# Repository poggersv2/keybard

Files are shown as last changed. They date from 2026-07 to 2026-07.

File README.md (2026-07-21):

# keybard (it's not misspelt)

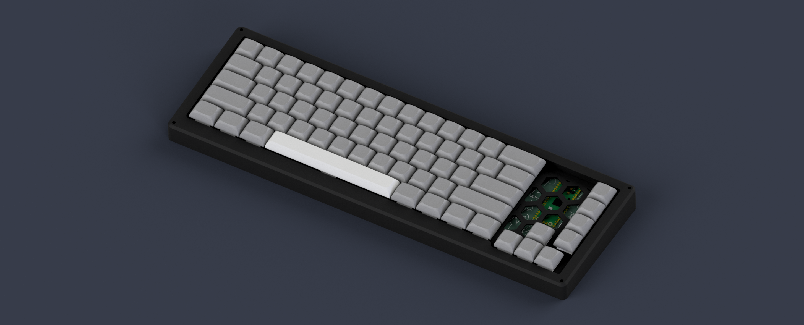
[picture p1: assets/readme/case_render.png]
Keybard


## Overview
**keybard** is a custom mechanical keyboard designed for Hackclub Keeb. Its a modified 60% layout, extended with a dedicated arrow key cluster and a column of macro keys on the side. 

The board is powered by a Raspberry Pi Pico (Orpheus Pico) and uses a sandwich mount case.

## Features
- **Layout:** Modified 60% + Arrow Keys + Macro Column
- **Microcontroller:** Raspberry Pi Pico / Orpheus Pico (RP2040)
- **Mounting Style:** Sandwich Mount
- **Firmware:** RMK with VIA support

## Why I Built It
Standard 60% keyboards are great for desk space but I wanted to have the arrow keys for productivity (and also games).

## What I Learned
Designing and building this board from scratch was kindda difficult: 

### 1. Switch Matrix 
Routing the matrix while making it look decent was hard.

### 2. Tolerances 
When designing the case, I found it hard to imagine the actual size of everything. The maths was a little hard to understand, but that got easier over time.

### 3. CAD
Before this project, I didn't really know how to use Fusion. I had to learn everything from scratch.

## Hardware Details

### Schematic
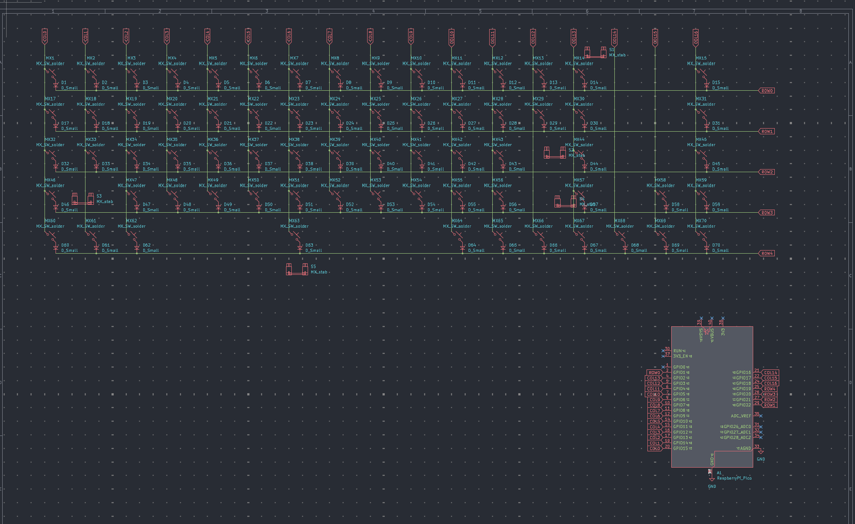
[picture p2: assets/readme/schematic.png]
Schematic


### PCB
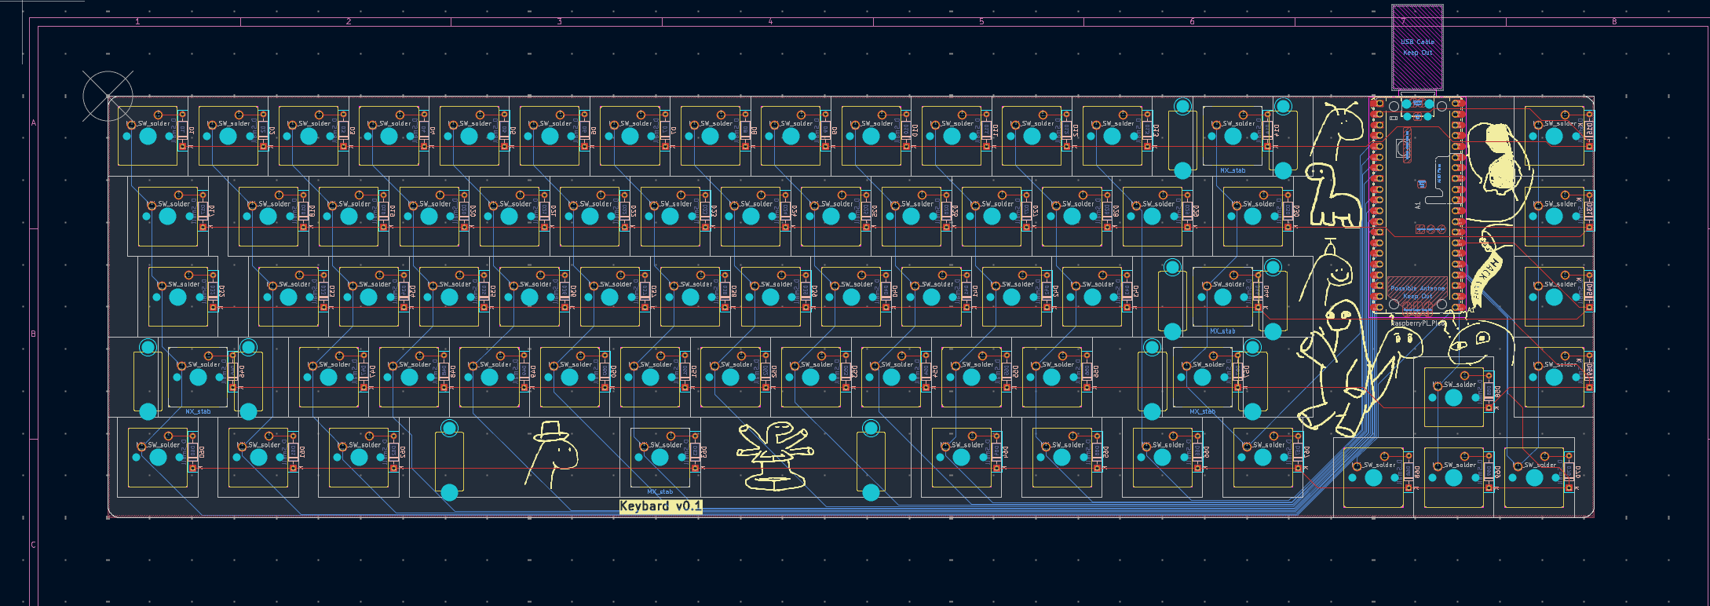
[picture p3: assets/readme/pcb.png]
PCB

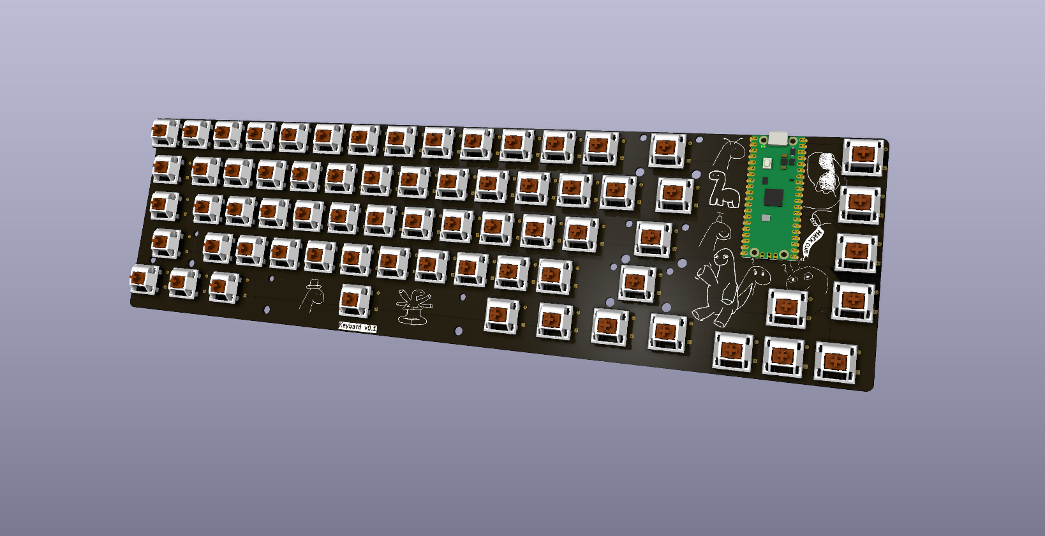
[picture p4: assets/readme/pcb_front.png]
PCB Front

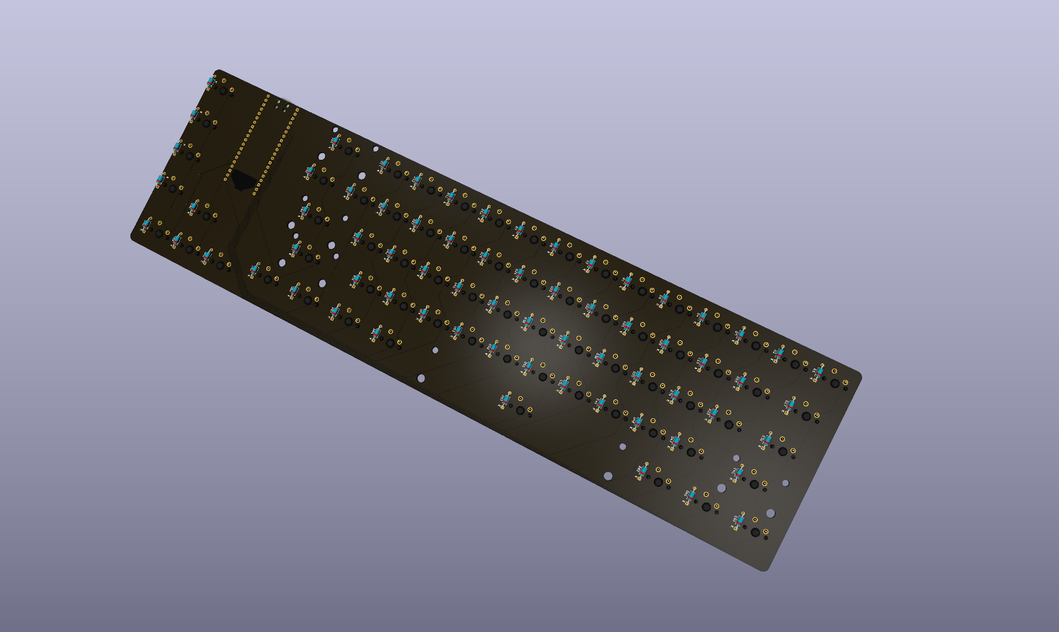
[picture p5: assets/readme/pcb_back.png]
PCB Back


### Case
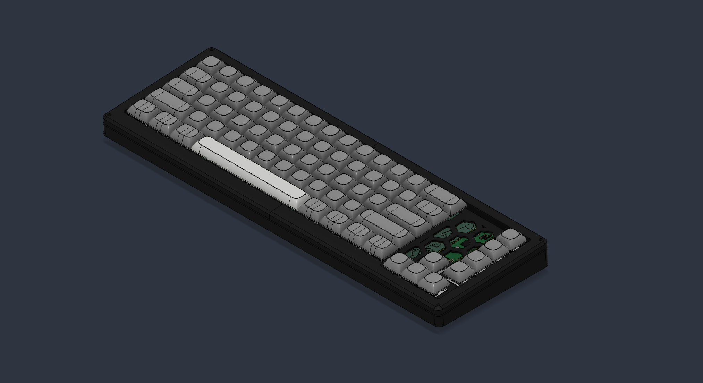
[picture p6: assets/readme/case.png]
Case


## Firmware
### How to Compile and Flash
### 1. Get the Firmware
1. Go to the **Actions** tab at the top of this GitHub repository.
2. Click on the latest successful run of the **Build RMK firmware** workflow.
3. Scroll down to the **Artifacts** section at the bottom of the page.
4. Download the compiled firmware `.zip` file and extract it to find your `.uf2` file.

### 2. Flash to the Keyboard
1. Unplug your keyboard.
2. Hold down the **BOOTSEL** button on your Raspberry Pi Pico.
3. While holding the button, plug the keyboard back into your computer via USB. 
4. A new mass storage drive will appear on your computer.
5. Drag and drop the `.uf2` firmware file into this drive.
6. The Pico will automatically reboot, and your keyboard is ready to use!

## Customization
### Keymap Editing (Vial)
This firmware is pre-configured with **Vial** , meaning you can remap your keys, setup macros, and change layers without needing to recompile firmware.

1. Download the Vial app or use the Web UI at [vial.rocks](https://vial.rocks/).
2. Plug in your keyboard and click **Authorize** (if using the web version) or let the app detect it.
3. Remap to your hearts content!

## Credits
* **Hack Club**
* **3D Models:** Cherry MX Switch model from [Thingiverse (2172302)](https://www.thingiverse.com/thing:2172302)
* **Layout Generation:** [Keyboard Tools Editor](https://editor.keyboard-tools.xyz/)
* **Firmware:** [RMK](https://rmk.rs/) and [Vial](https://vial.rocks/)

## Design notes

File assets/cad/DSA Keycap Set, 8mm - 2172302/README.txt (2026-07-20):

DSA Keycap Set, 8mm by kaelruland on Thingiverse: https://www.thingiverse.com/thing:2172302

Summary:
The new home of my DSA keycap project. This set includes 1u, 1u homing, 1.25u, 1.5u, 1.75u, 2u, 2.25u and 2.75u keys and a 6.25u spacebar. Mounts are standard MX. The 2u, 2.25u and 2.75u keys have three mounts spaced at 12mm from the center. The 6.25u spacebar has three mounts @ 50mm from the center. Mounts are flush with the bottom of the key so supports shouldn't be necessary. All keycaps are 18.2mm wide and n*(19mm) - 0.8mm long, where n is the unit length of the key. The height of the key is just under 8mm and the depth of the touch surface is 0.9mm below that. Minimum wall thickness is 1.8mm.

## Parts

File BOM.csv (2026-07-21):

Item | Quantity | Unit price (USD) | Price (USD) | Description/Specification | Source
Keycaps | 69 | $15.00 | $15.00 | Blank set of keycaps | https://www.aliexpress.com/item/1005005976474831.html?curPageLogUid=R90zIkfRGreX
Switches | 69 | $13.51 | $13.51 | Blue switches | https://www.aliexpress.com/item/1005002378701948.html?gatewayAdapt=usa2glo4itemAdapt
Diodes | 69 | $0.06 | $4.14 | 1N4148 | https://www.digikey.co.nz/en/products/detail/onsemi/1N4148/458603
Screws | 4 | $2.28 | $2.28 | M3 x 16mm | https://www.aliexpress.com/ssr/300000512/BundleDeals2?productIds=1005006904738286:12000058886763706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
Heatset Inserts | 4 | $5.85 | $5.85 | M3 x 5mm x 4mm | https://www.aliexpress.com/item/4000232858343.html?gatewayAdapt=usa2glo4itemAdapt&_randl_shipto=NZ
Microcontroller | 1 | 0 | $0.00 | Orpheus Pico
Stablizers | 1 | $4.35 | $4.35 | 4x 2U + 6.25U | https://www.aliexpress.com/item/1005004229140548.html?curPageLogUid=NnlyZwOGxuXr
 |  | Total (USD) | $45.13

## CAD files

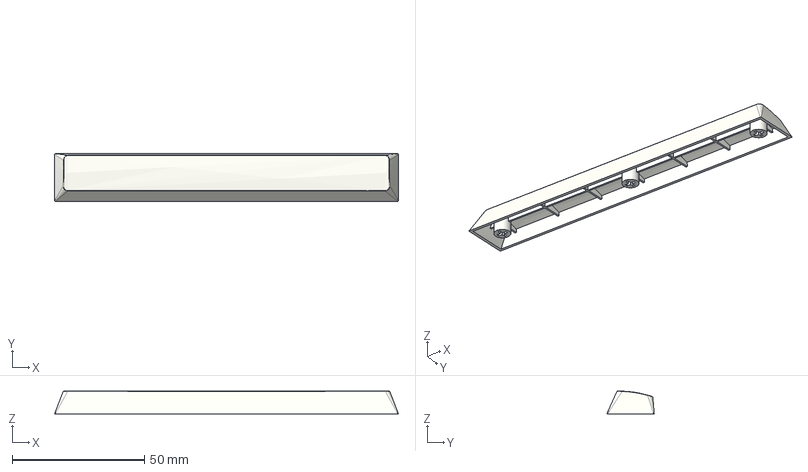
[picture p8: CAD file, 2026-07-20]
assets/cad/6.25U keycap.step
130.2 x 18.0 x 8.70 mm

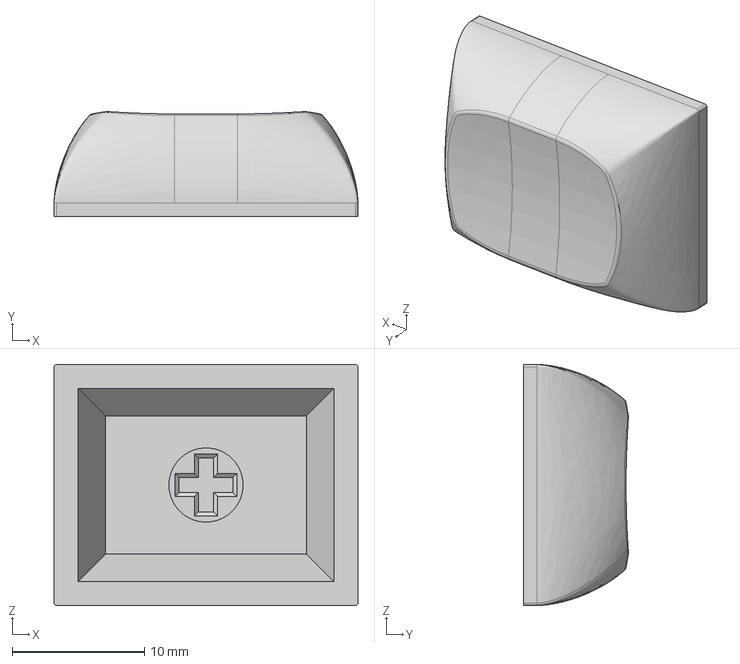
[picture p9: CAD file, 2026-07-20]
assets/cad/DSA Keycap Set, 8mm - 2172302/files/DSA_1.25u.step
22.9 x 7.91 x 18.2 mm

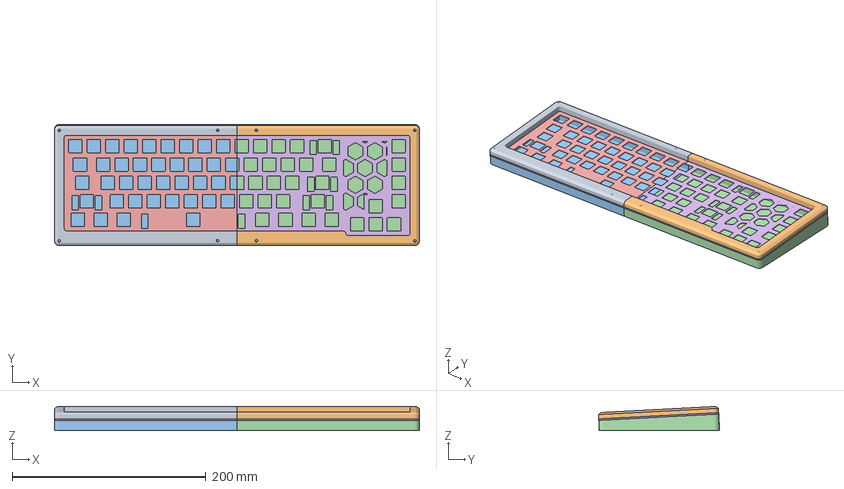
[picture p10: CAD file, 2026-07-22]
cad/case.3mf
376.4 x 124.9 x 24.8 mm
bezel (left)
bezel (right)
bottom (left)
bottom (right)
plate (left)
plate (right)

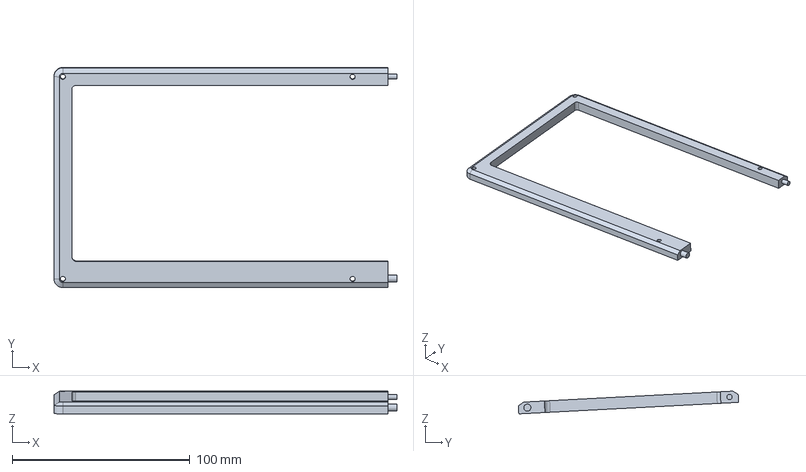
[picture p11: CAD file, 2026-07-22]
production/cad/left side/bezel(left).step
193.2 x 124.1 x 12.8 mm

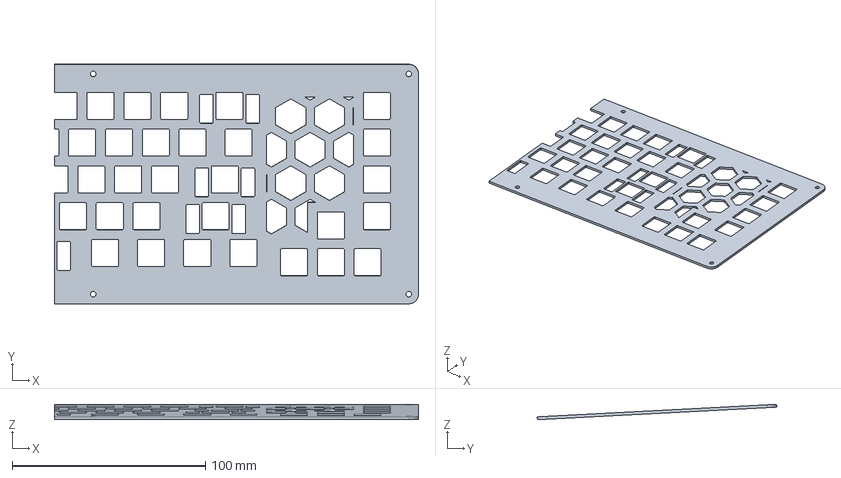
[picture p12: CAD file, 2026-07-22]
production/cad/right side/plate(right).step
188.2 x 123.9 x 7.99 mm

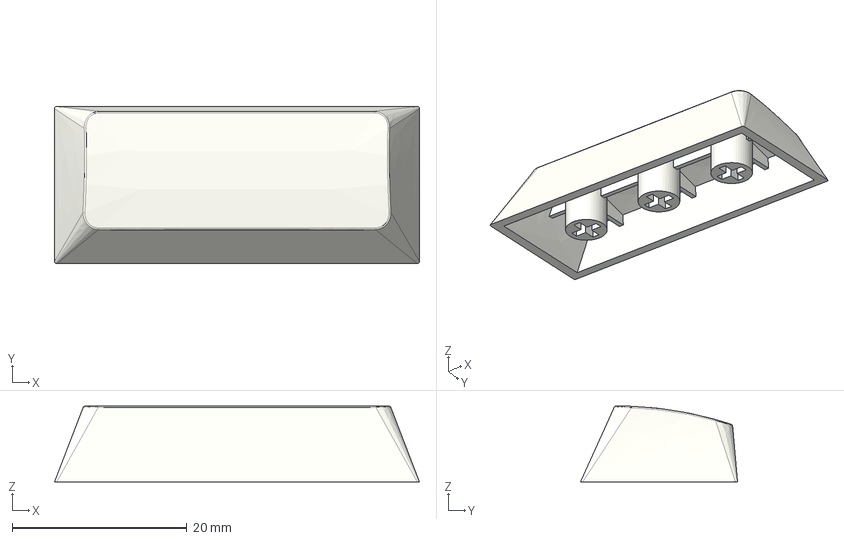
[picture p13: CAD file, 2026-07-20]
assets/cad/1U keycap (v1).step
41.8 x 18.0 x 8.70 mm

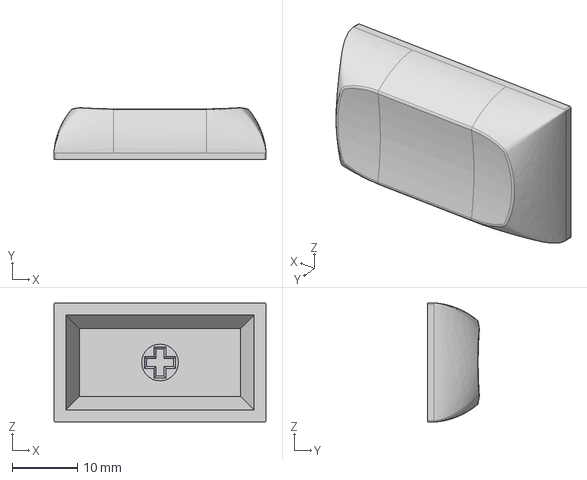
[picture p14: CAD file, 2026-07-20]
assets/cad/DSA Keycap Set, 8mm - 2172302/files/DSA_1.75u.step
32.5 x 7.91 x 18.2 mm

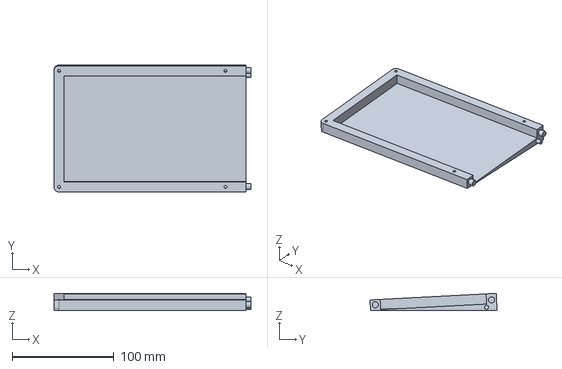
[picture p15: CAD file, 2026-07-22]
production/cad/left side/bottom(left).step
193.2 x 124.6 x 17.0 mm

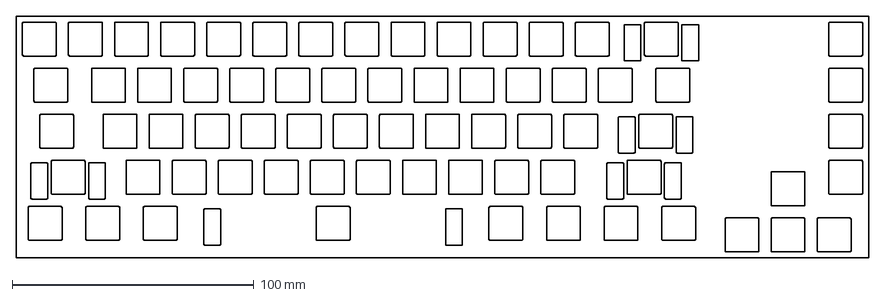
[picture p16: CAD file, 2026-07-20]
assets/cad/plate-2026-07-20T06_56_22.009Z.dxf
352.4 x 100.0 mm

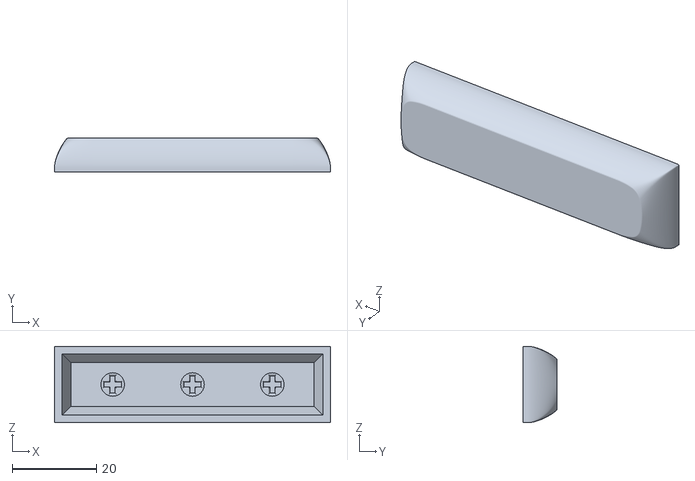
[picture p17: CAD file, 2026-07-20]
assets/cad/DSA Keycap Set, 8mm - 2172302/files/DSA_Spacebar_3.5u_38mm_spacing.stl
65.7 x 8.00 x 18.2

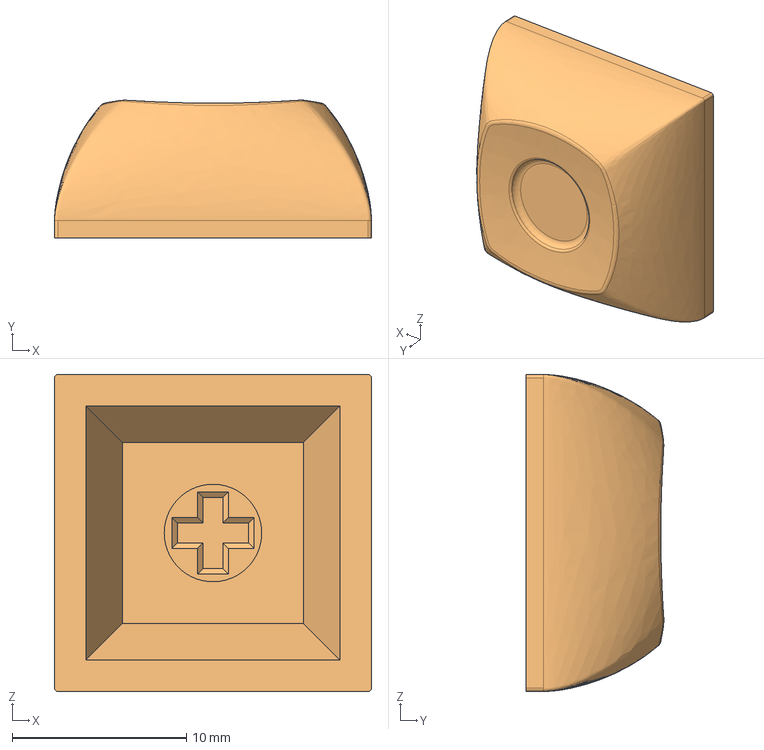
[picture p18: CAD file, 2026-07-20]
assets/cad/DSA Keycap Set, 8mm - 2172302/files/DSA_1u_homing.step
18.2 x 7.91 x 18.2 mm

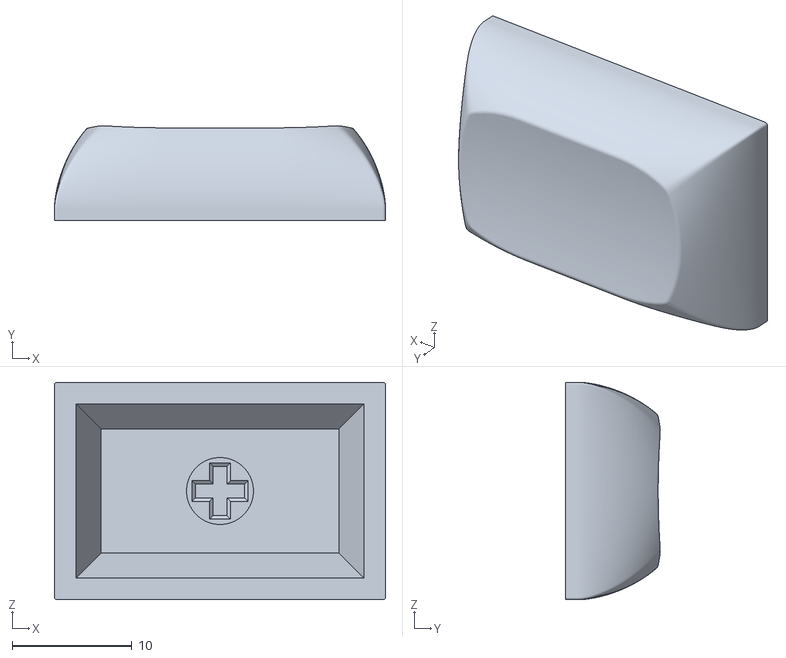
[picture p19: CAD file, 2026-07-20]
assets/cad/DSA Keycap Set, 8mm - 2172302/files/DSA_1.5.stl
27.7 x 7.91 x 18.2

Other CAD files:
production/cad/right side/bottom(right).step
production/cad/left side/plate(left).step
production/cad/right side/bezel(right).step
assets/cad/1U keycap.step
assets/cad/DSA Keycap Set, 8mm - 2172302/files/DSA_1u.step
assets/cad/DSA Keycap Set, 8mm - 2172302/files/DSA_1.25u.stl
assets/cad/DSA Keycap Set, 8mm - 2172302/files/DSA_1.5u.step
assets/cad/DSA Keycap Set, 8mm - 2172302/files/DSA_1.75u.stl
assets/cad/DSA Keycap Set, 8mm - 2172302/files/DSA_1u.stl
assets/cad/DSA Keycap Set, 8mm - 2172302/files/DSA_1u_homing.stl
assets/cad/DSA Keycap Set, 8mm - 2172302/files/DSA_2.25u.step
assets/cad/DSA Keycap Set, 8mm - 2172302/files/DSA_2.25u.stl
assets/cad/DSA Keycap Set, 8mm - 2172302/files/DSA_2.75u.step
assets/cad/DSA Keycap Set, 8mm - 2172302/files/DSA_2.75u.stl
assets/cad/DSA Keycap Set, 8mm - 2172302/files/DSA_2u.step
assets/cad/DSA Keycap Set, 8mm - 2172302/files/DSA_2u.stl
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

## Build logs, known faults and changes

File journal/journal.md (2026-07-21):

# keybard Journal

## Entry 1: Layout Editor
**Time Spent:** 0.5 hours

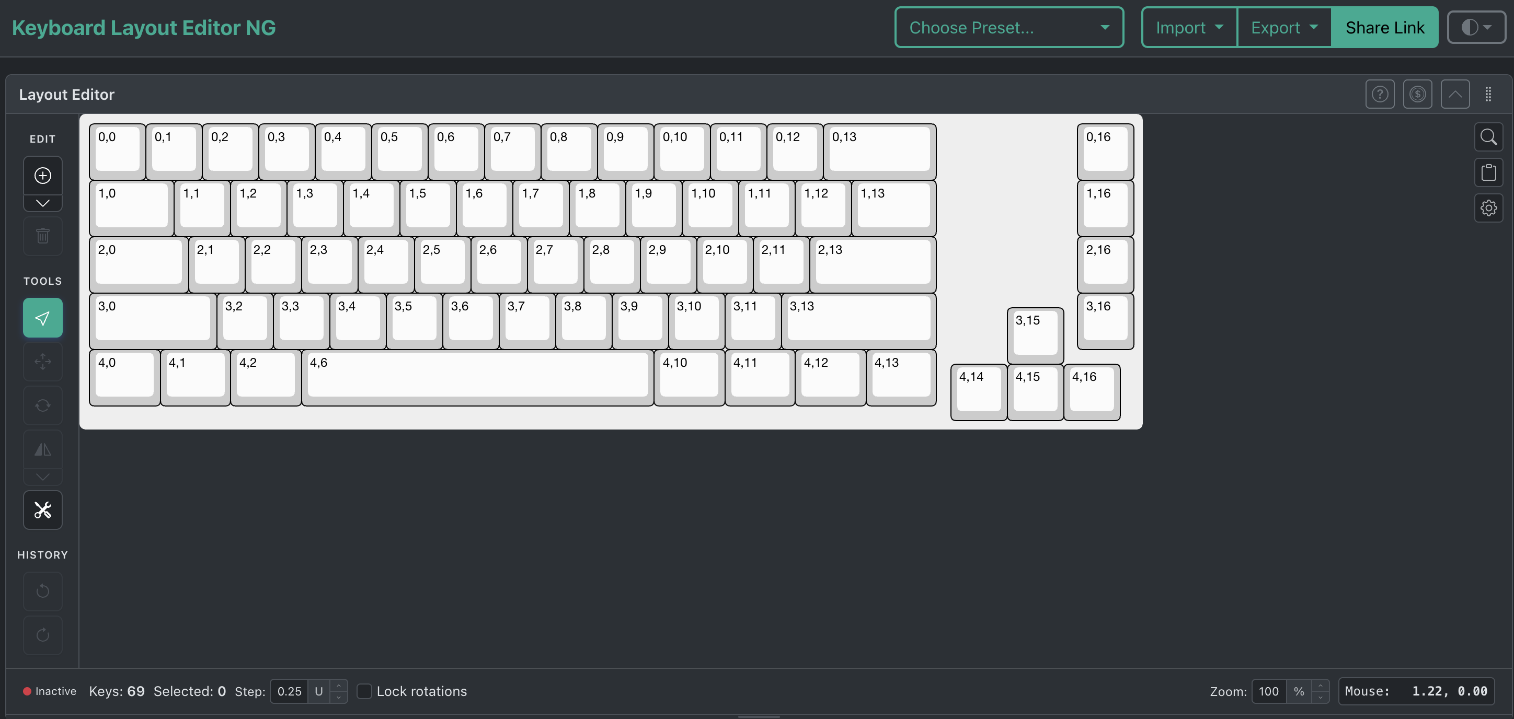
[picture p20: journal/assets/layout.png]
Layout Editor


**What I did:** 
I started by generating layout for the board using Keyboard Layout Editor NG (https://editor.keyboard-tools.xyz/). I took a standard 60% layout and extended it to include the arrow key cluster and the side macro column, with spacing in between the macros and the keyboard to leave space for the Pico.
**What I got stuck on:** 
Figuring out how to space the macro keys and arrows so they look smooth with the rest of the board. It took a bit of tweaking before I was happy with the final layout.

---

## Entry 2: Schematic
**Time Spent:** 1.0 hours

Schematic

**What I did:** 
I started to wiring up the schematic. I set up the Pico and added the 5x17 matrix for the switches. 
**What I got stuck on:** 
Making sure all the GPIO pins from the Pico matched up correctly with the rows and columns without any overlapping took some ages, and I had to quadruple check it because it was a little confusing.

---

## Entry 3: PCB
**Time Spent:** 2.0 hours

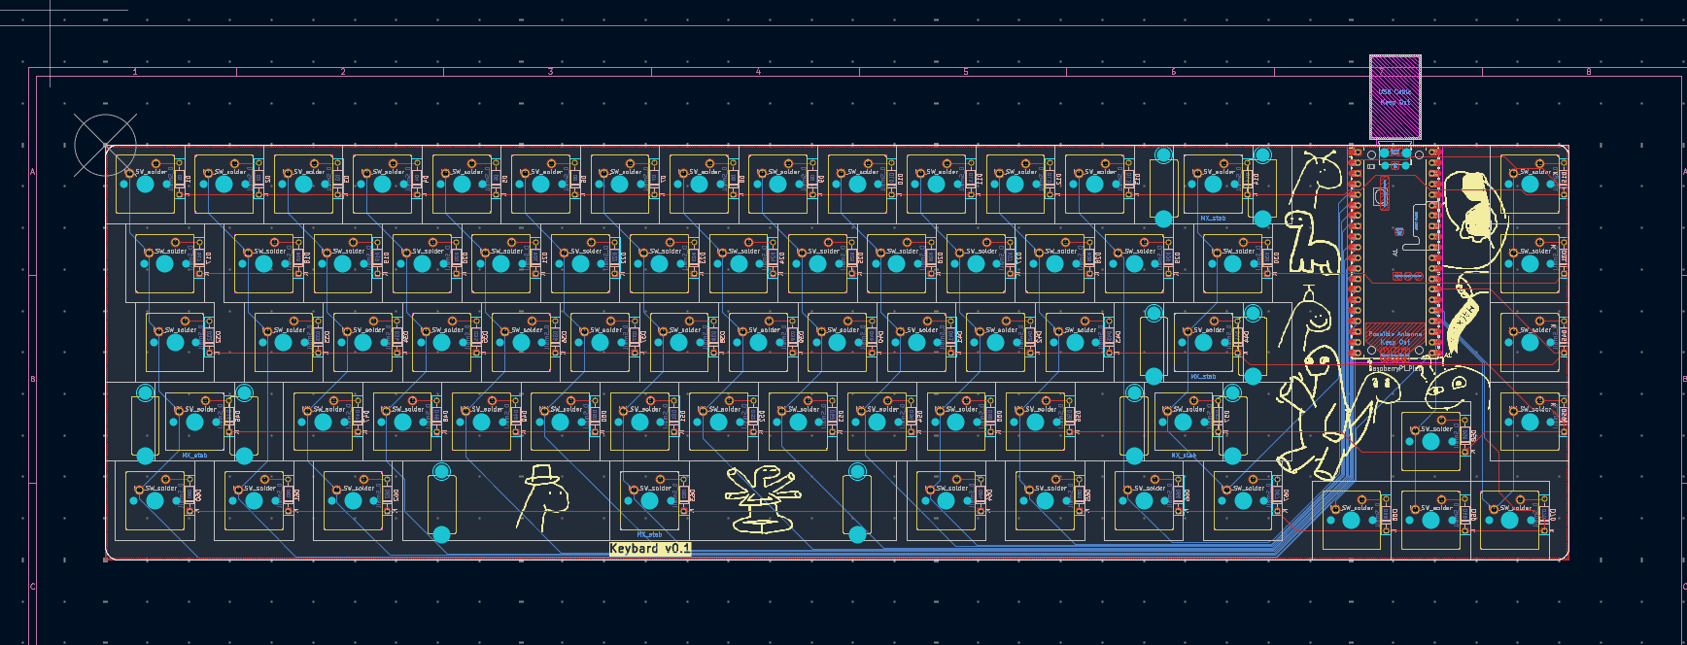
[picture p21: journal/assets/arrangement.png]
PCB Arrangement


**What I did:** 
I moved on to the actual PCB layout. I imported the JSON that I exported for KLE NG and used an extention to place the switch footprints for me. Then I arranged the Pico to where I wanted it and got to routing everything
**What I got stuck on:** 
Didn't get stuck on anything, but the alignment and grid system of KiCad was kindda hard to understand.

---

## Entry 4: Routing the PCB
**Time Spent:** 2.0 hours

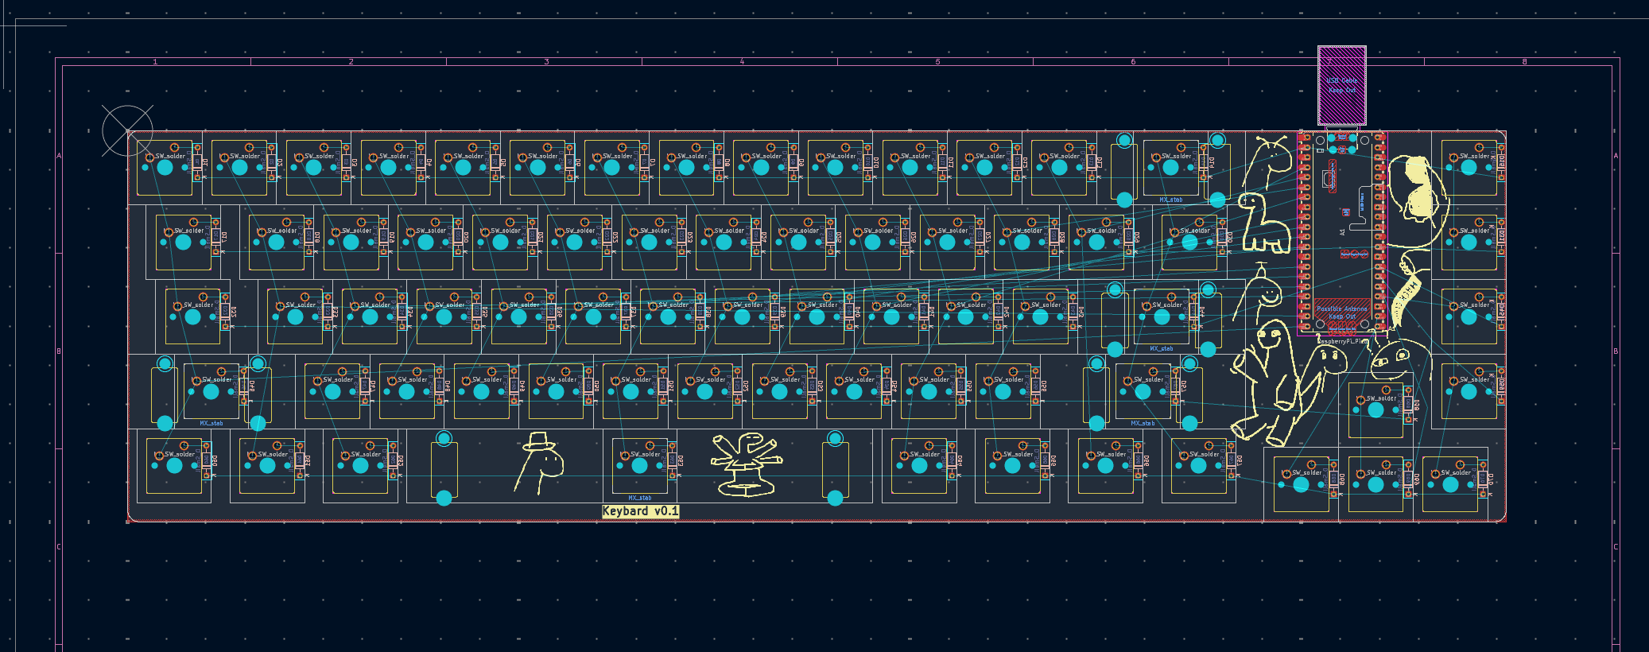
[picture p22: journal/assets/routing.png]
PCB Routing


**What I did:** 
Spent AGES routing all the traces across the board and wiring the rows and columns back to the Pico's pins.
**What I got stuck on:** 
Routing the matrix to make it actually work while also trying to keep the traces looking decent was definitely one of the hardest parts.

---

## Entry 5: Case Design (Plate)
**Time Spent:** 2.0 hours

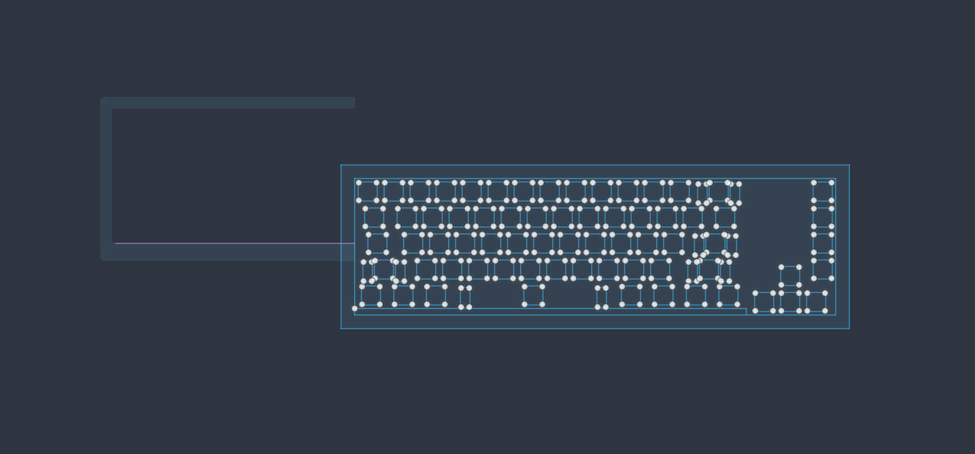
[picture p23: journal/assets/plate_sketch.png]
Plate Sketch


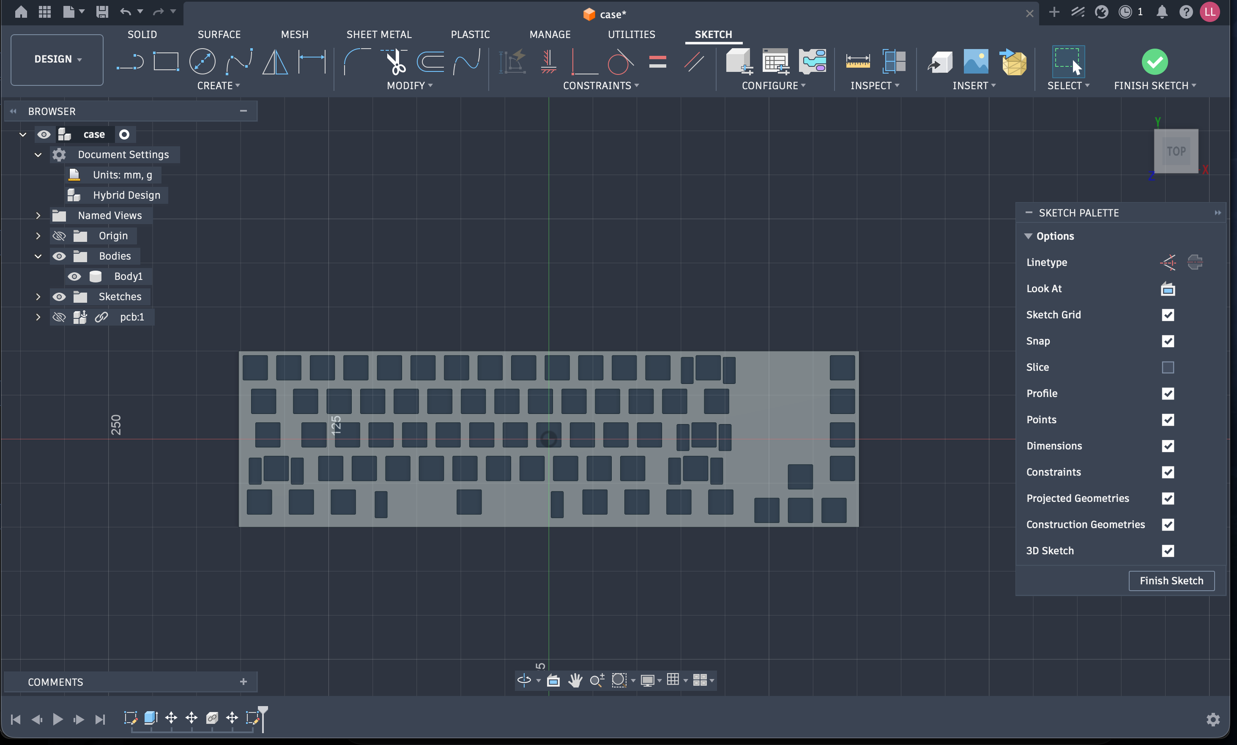
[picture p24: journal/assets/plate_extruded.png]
Switch Plate


**What I did:** 
Started learning CAD completely from scratch using Fusion. I started by importing the plate I downloaded from KLE NG. I added tolerances and the outer case and extruded it by 1.5mm
**What I got stuck on:** 
I had zero experience with Fusion, so just figuring out the UI and the basic tools took up a long time.

---

## Entry 6: Case Design (Bezel / Top)
**Time Spent:** 1.5 hours

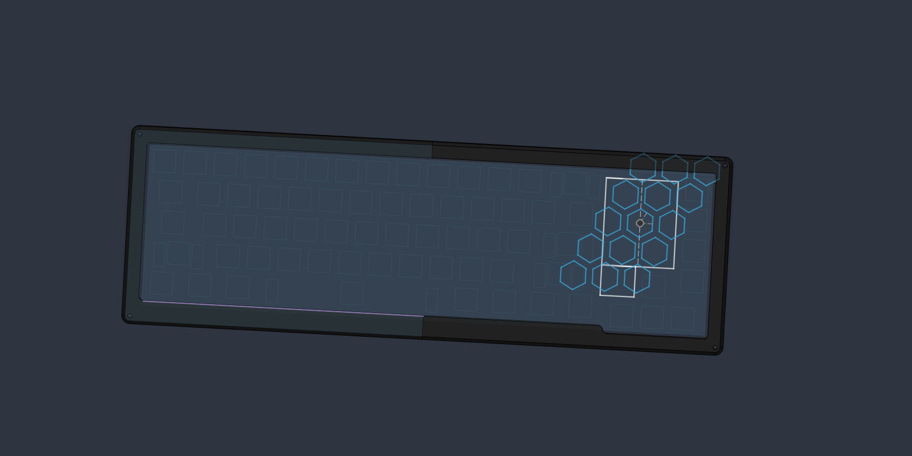
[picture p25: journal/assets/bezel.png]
Top Bezel


**What I did:** 
Extruded the top bezel pieces to frame the keyboard. I had to account for the height of the switches and keycaps so the board looks nice. I added a chamfer to the edges so it's not sharp
**What I got stuck on:** 
Distances and tolerances were super hard to imagine the actual physical size of everything on a screen, and doing the math for the clearance gaps and spacings was hard at first.

---

## Entry 7: Case Design (Bottom & Assembly)
**Time Spent:** 2.0 hours

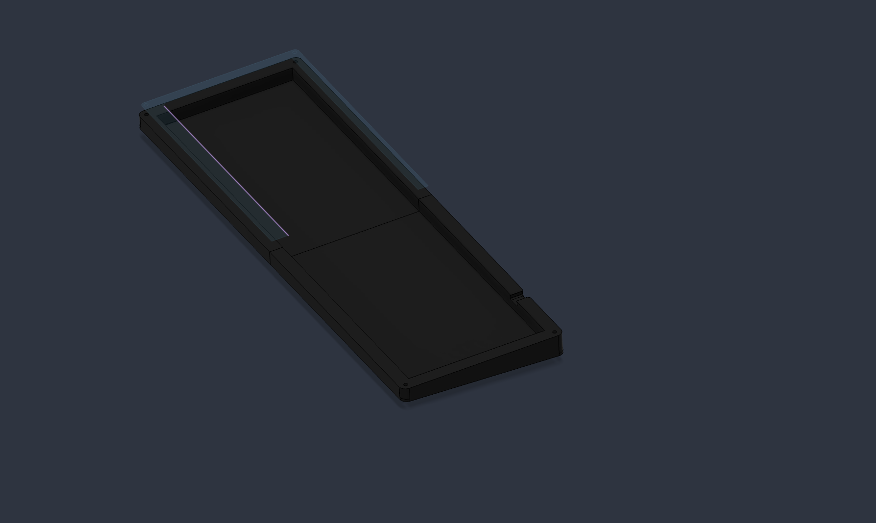
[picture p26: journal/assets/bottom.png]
Case Bottom


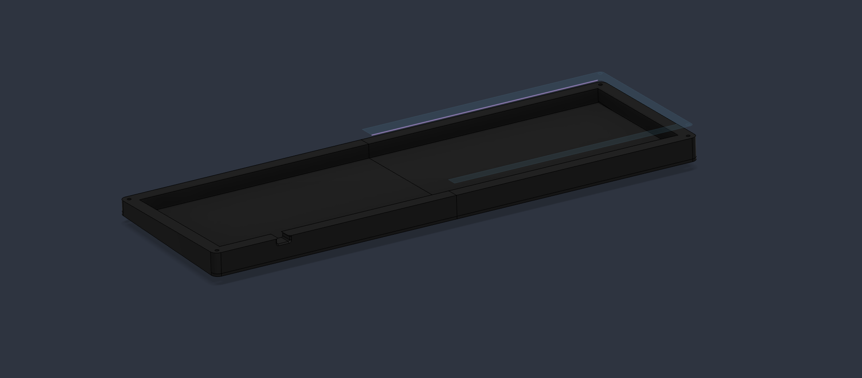
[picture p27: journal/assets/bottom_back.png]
Case Bottom Back


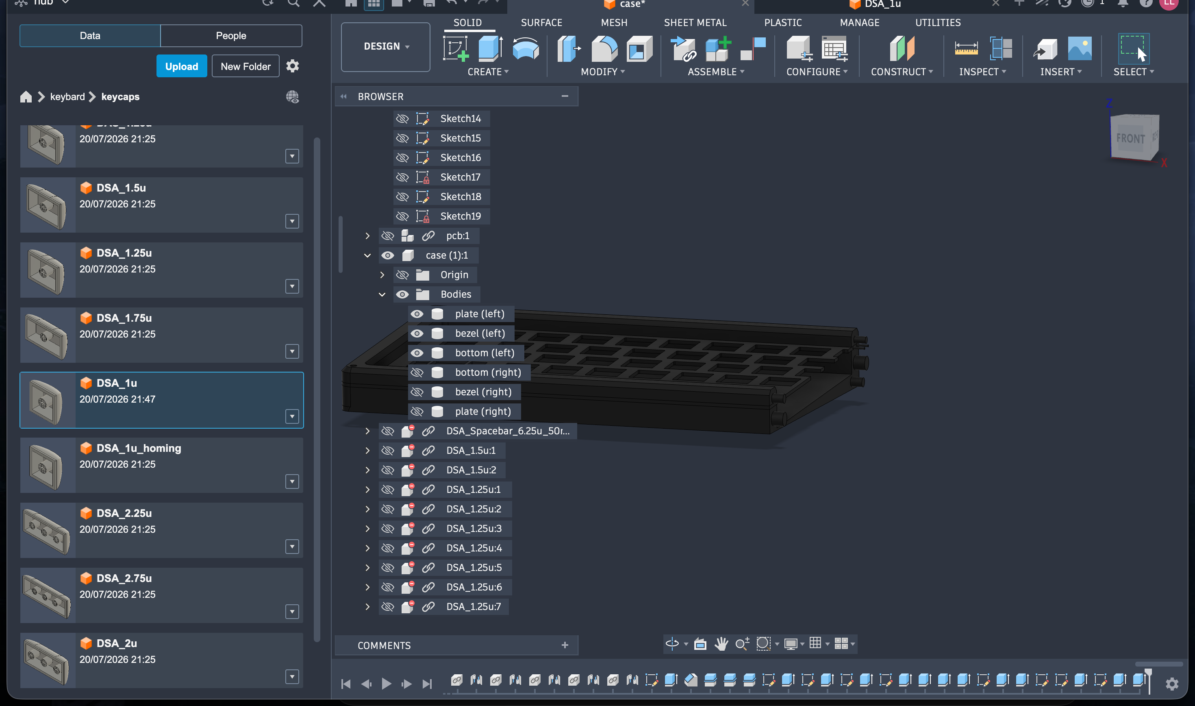
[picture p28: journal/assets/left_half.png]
Left Half


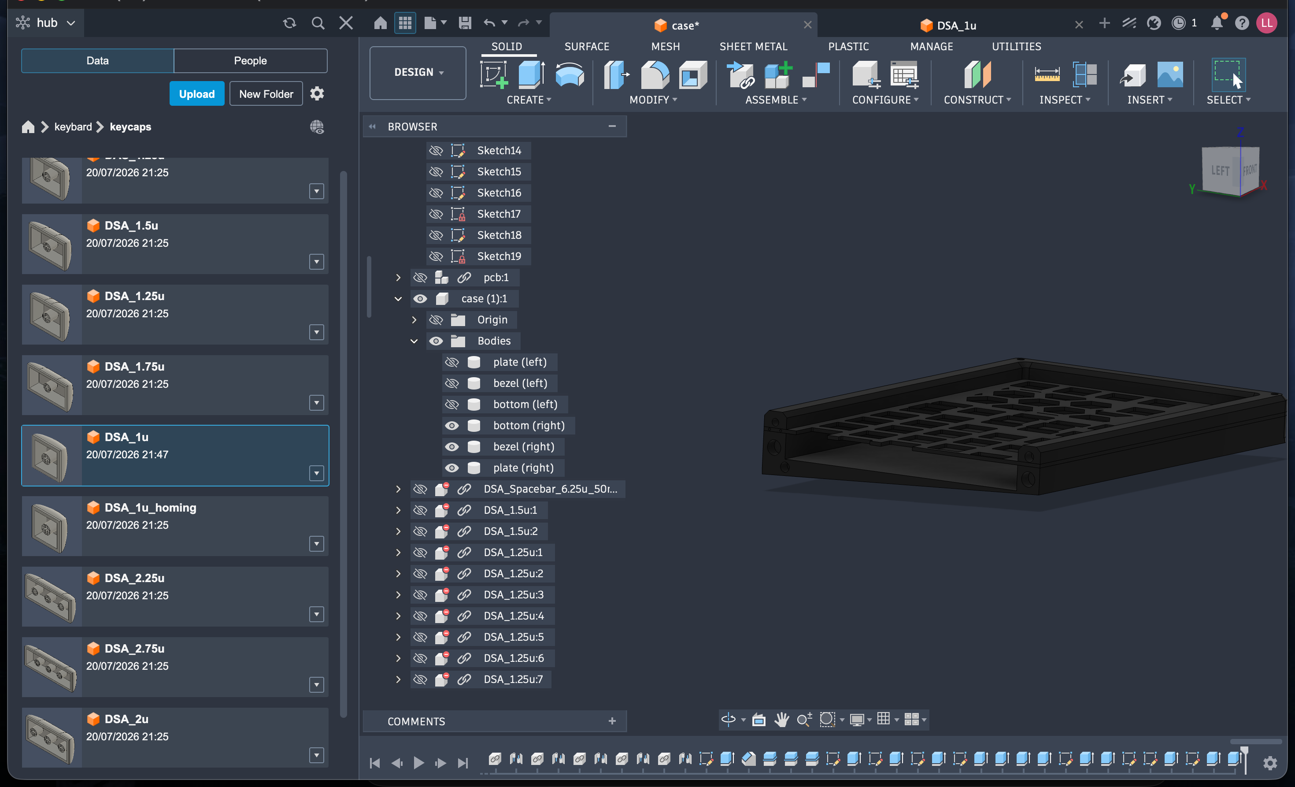
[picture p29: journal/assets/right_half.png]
Right Half


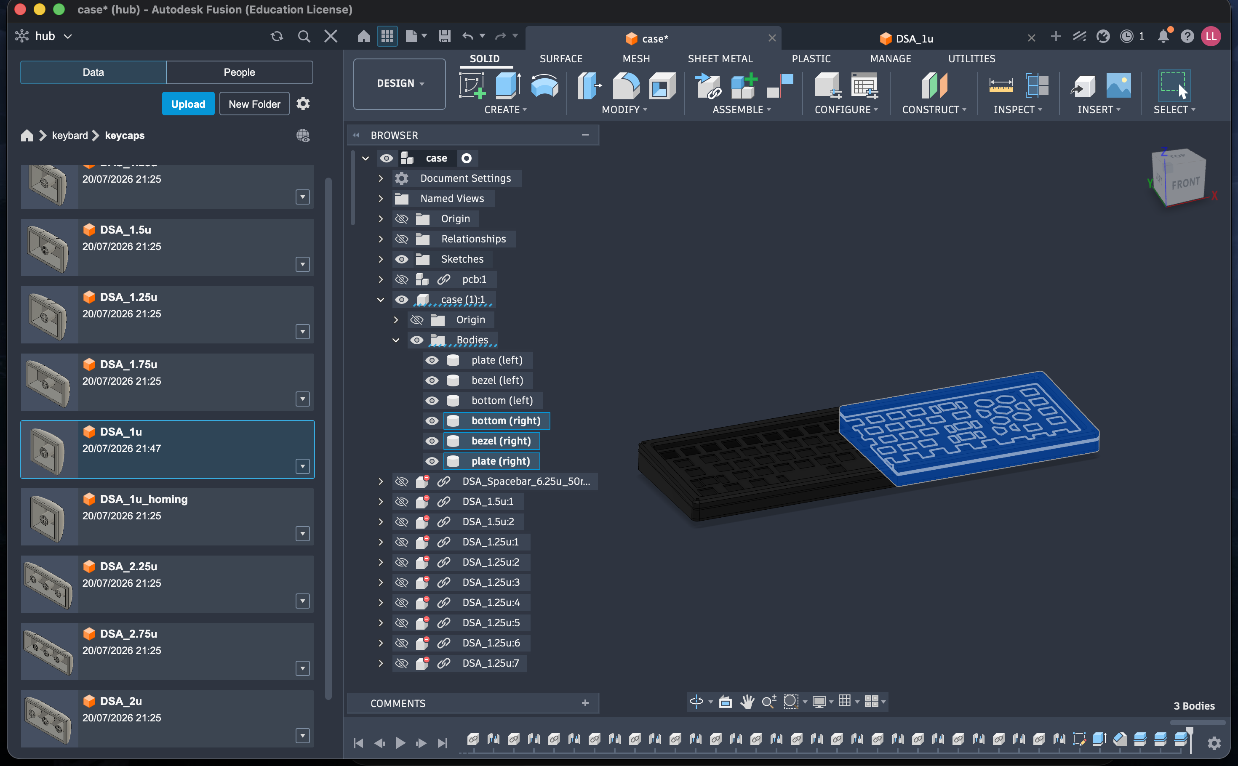
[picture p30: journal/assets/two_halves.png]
Two Halves Assembled


**What I did:** 
Finished off the case by designing the bottom plate and adding all the mounting holes so it can actually be screwed together. Then I exported everything for manufacturing. I had to split the case into 6 seperate parts because it didn't fit on a 3d printer plate.

**What I got stuck on:** 
Using the right tools.

---

## Entry 8: Firmware Setup
**Time Spent:** 1.5 hours

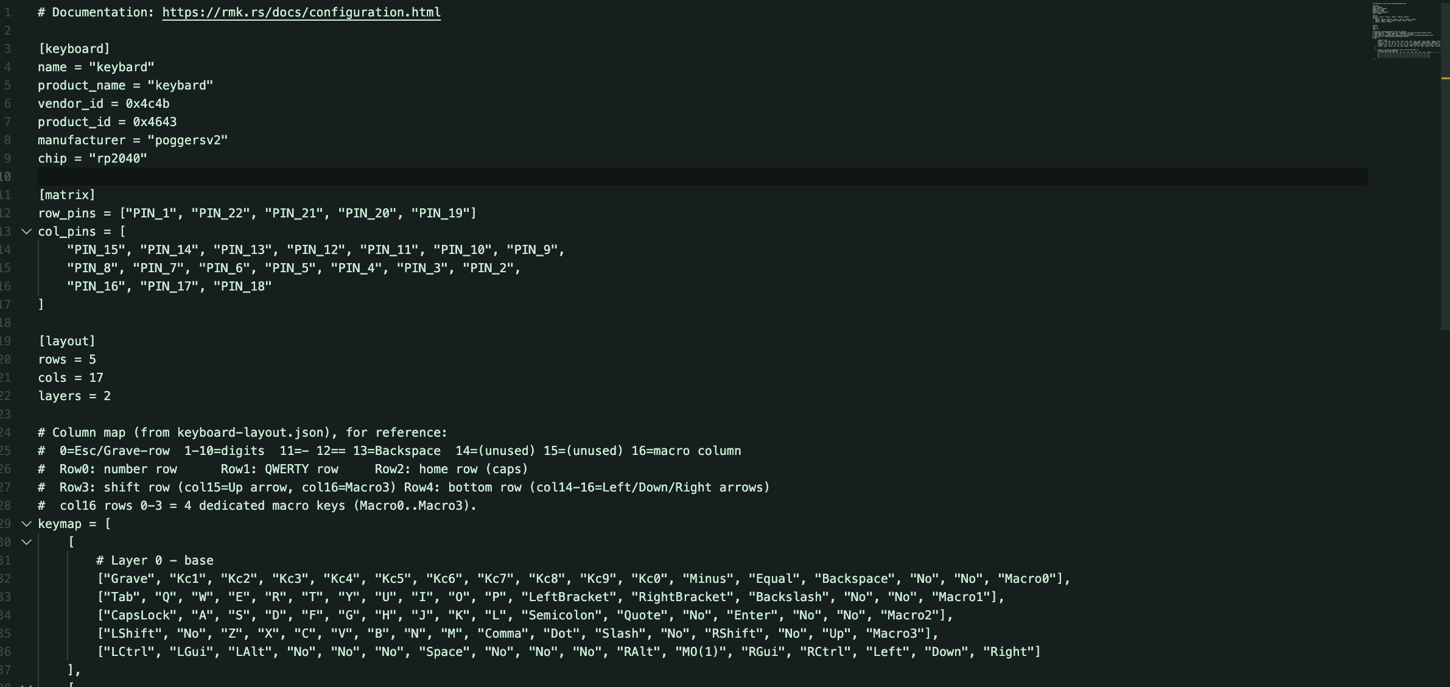
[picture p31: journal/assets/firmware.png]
Firmware Code


**What I did:** 
I set up the RMK firmware framework using GitHub Actions so it just compiles on Github. I mapped the matrix in `keyboard.toml` to match my schematic and set up the default layout and macros in `vial.json`. 
**What I got stuck on:** 
Mapping the keys was kindda confusing.

# Total Time Spent: `15.5` Hours

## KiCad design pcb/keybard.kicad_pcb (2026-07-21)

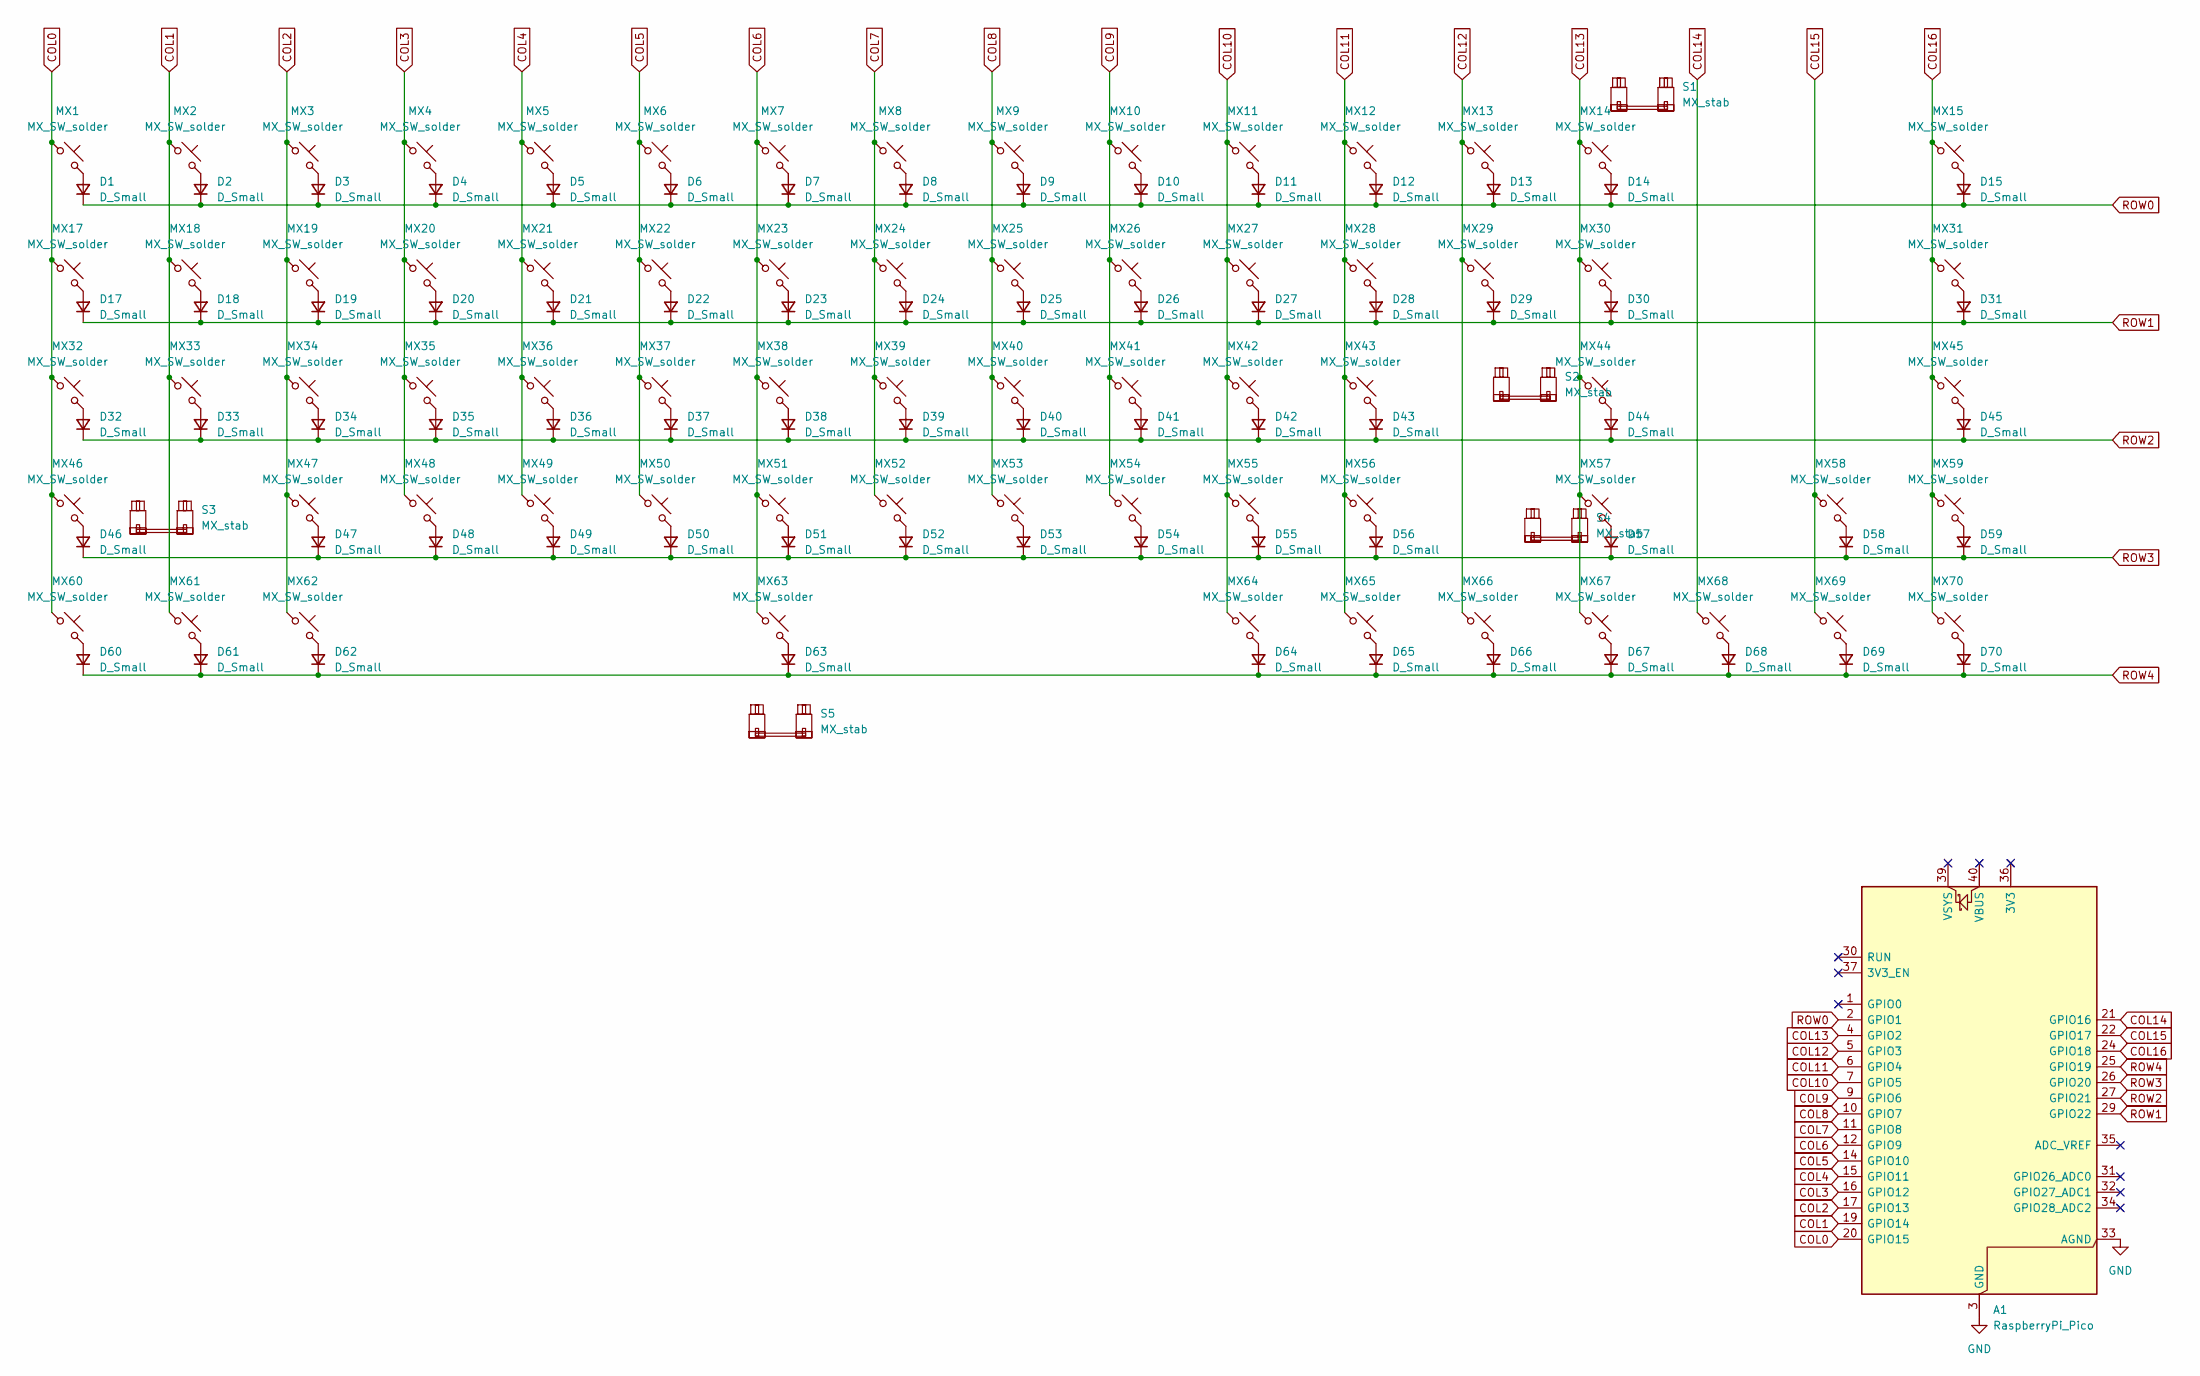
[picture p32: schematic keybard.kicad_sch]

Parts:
A1: RaspberryPi_Pico; RaspberryPi_Pico_Common_Unspecified
D1, D2, D3, D4, D5, D6, D7, D8, D9, D10, D11, D12, D13, D14, D15, D17, D18, D19, D20, D21, D22, D23, D24, D25, D26, D27, D28, D29, D30, D31, D32, D33, D34, D35, D36, D37, D38, D39, D40, D41, D42, D43, D44, D45, D46, D47, D48, D49, D50, D51, D52, D53, D54, D55, D56, D57, D58, D59, D60, D61, D62, D63, D64, D65, D66, D67, D68, D69, D70: D_Small; D_DO-35_SOD27_P7.62mm_Horizontal
MX1, MX2, MX3, MX4, MX5, MX6, MX7, MX8, MX9, MX10, MX11, MX12, MX13, MX14, MX15, MX17, MX18, MX19, MX20, MX21, MX22, MX23, MX24, MX25, MX26, MX27, MX28, MX29, MX30, MX31, MX32, MX33, MX34, MX35, MX36, MX37, MX38, MX39, MX40, MX41, MX42, MX43, MX44, MX45, MX46, MX47, MX48, MX49, MX50, MX51, MX52, MX53, MX54, MX55, MX56, MX57, MX58, MX59, MX60, MX61, MX62, MX63, MX64, MX65, MX66, MX67, MX68, MX69, MX70: MX_SW_solder; SW_MX_1u
S1: MX_stab; STAB_MX_2u
S2, S3: MX_stab; STAB_MX_2.25u
S4: MX_stab; STAB_MX_2.75u
S5: MX_stab; STAB_MX_6.25u

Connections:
COL0: A1.20 (GPIO15), MX1.1, MX17.1, MX32.1, MX46.1, MX60.1
COL1: A1.19 (GPIO14), MX2.1, MX18.1, MX33.1, MX61.1
COL2: A1.17 (GPIO13), MX3.1, MX19.1, MX34.1, MX47.1, MX62.1
COL3: A1.16 (GPIO12), MX4.1, MX20.1, MX35.1, MX48.1
COL4: A1.15 (GPIO11), MX5.1, MX21.1, MX36.1, MX49.1
COL5: A1.14 (GPIO10), MX6.1, MX22.1, MX37.1, MX50.1
COL6: A1.12 (GPIO9), MX7.1, MX23.1, MX38.1, MX51.1, MX63.1
COL7: A1.11 (GPIO8), MX8.1, MX24.1, MX39.1, MX52.1
COL8: A1.10 (GPIO7), MX9.1, MX25.1, MX40.1, MX53.1
COL9: A1.9 (GPIO6), MX10.1, MX26.1, MX41.1, MX54.1
COL10: A1.7 (GPIO5), MX11.1, MX27.1, MX42.1, MX55.1, MX64.1
COL11: A1.6 (GPIO4), MX12.1, MX28.1, MX43.1, MX56.1, MX65.1
COL12: A1.5 (GPIO3), MX13.1, MX29.1, MX66.1
COL13: A1.4 (GPIO2), MX14.1, MX30.1, MX44.1, MX57.1, MX67.1
COL14: A1.21 (GPIO16), MX68.1
COL15: A1.22 (GPIO17), MX58.1, MX69.1
COL16: A1.24 (GPIO18), MX15.1, MX31.1, MX45.1, MX59.1, MX70.1
GND: A1.3 (GND), A1.8 (GND), A1.13 (GND), A1.18 (GND), A1.23 (GND), A1.28 (GND), A1.33 (AGND), A1.38 (GND)
unnamed: D1.2 (A), MX1.2
unnamed: D2.2 (A), MX2.2
unnamed: D3.2 (A), MX3.2
unnamed: D4.2 (A), MX4.2
unnamed: D5.2 (A), MX5.2
unnamed: D6.2 (A), MX6.2
unnamed: D7.2 (A), MX7.2
unnamed: D8.2 (A), MX8.2
unnamed: D9.2 (A), MX9.2
unnamed: D10.2 (A), MX10.2
unnamed: D11.2 (A), MX11.2
unnamed: D12.2 (A), MX12.2
unnamed: D13.2 (A), MX13.2
unnamed: D14.2 (A), MX14.2
unnamed: D15.2 (A), MX15.2
unnamed: D17.2 (A), MX17.2
unnamed: D18.2 (A), MX18.2
unnamed: D19.2 (A), MX19.2
unnamed: D20.2 (A), MX20.2
unnamed: D21.2 (A), MX21.2
unnamed: D22.2 (A), MX22.2
unnamed: D23.2 (A), MX23.2
unnamed: D24.2 (A), MX24.2
unnamed: D25.2 (A), MX25.2
unnamed: D26.2 (A), MX26.2
unnamed: D27.2 (A), MX27.2
unnamed: D28.2 (A), MX28.2
unnamed: D29.2 (A), MX29.2
unnamed: D30.2 (A), MX30.2
unnamed: D31.2 (A), MX31.2
unnamed: D32.2 (A), MX32.2
unnamed: D33.2 (A), MX33.2
unnamed: D34.2 (A), MX34.2
unnamed: D35.2 (A), MX35.2
unnamed: D36.2 (A), MX36.2
unnamed: D37.2 (A), MX37.2
unnamed: D38.2 (A), MX38.2
unnamed: D39.2 (A), MX39.2
unnamed: D40.2 (A), MX40.2
unnamed: D41.2 (A), MX41.2
unnamed: D42.2 (A), MX42.2
unnamed: D43.2 (A), MX43.2
unnamed: D44.2 (A), MX44.2
unnamed: D45.2 (A), MX45.2
unnamed: D46.2 (A), MX46.2
unnamed: D47.2 (A), MX47.2
unnamed: D48.2 (A), MX48.2
unnamed: D49.2 (A), MX49.2
unnamed: D50.2 (A), MX50.2
unnamed: D51.2 (A), MX51.2
unnamed: D52.2 (A), MX52.2
unnamed: D53.2 (A), MX53.2
unnamed: D54.2 (A), MX54.2
unnamed: D55.2 (A), MX55.2
unnamed: D56.2 (A), MX56.2
unnamed: D57.2 (A), MX57.2
unnamed: D58.2 (A), MX58.2
unnamed: D59.2 (A), MX59.2
unnamed: D60.2 (A), MX60.2
unnamed: D61.2 (A), MX61.2
unnamed: D62.2 (A), MX62.2
unnamed: D63.2 (A), MX63.2
unnamed: D64.2 (A), MX64.2
unnamed: D65.2 (A), MX65.2
unnamed: D66.2 (A), MX66.2
unnamed: D67.2 (A), MX67.2
unnamed: D68.2 (A), MX68.2
unnamed: D69.2 (A), MX69.2
unnamed: D70.2 (A), MX70.2
ROW0: A1.2 (GPIO1), D1.1 (K), D2.1 (K), D3.1 (K), D4.1 (K), D5.1 (K), D6.1 (K), D7.1 (K), D8.1 (K), D9.1 (K), D10.1 (K), D11.1 (K), D12.1 (K), D13.1 (K), D14.1 (K), D15.1 (K)
ROW1: A1.29 (GPIO22), D17.1 (K), D18.1 (K), D19.1 (K), D20.1 (K), D21.1 (K), D22.1 (K), D23.1 (K), D24.1 (K), D25.1 (K), D26.1 (K), D27.1 (K), D28.1 (K), D29.1 (K), D30.1 (K), D31.1 (K)
ROW2: A1.27 (GPIO21), D32.1 (K), D33.1 (K), D34.1 (K), D35.1 (K), D36.1 (K), D37.1 (K), D38.1 (K), D39.1 (K), D40.1 (K), D41.1 (K), D42.1 (K), D43.1 (K), D44.1 (K), D45.1 (K)
ROW3: A1.26 (GPIO20), D46.1 (K), D47.1 (K), D48.1 (K), D49.1 (K), D50.1 (K), D51.1 (K), D52.1 (K), D53.1 (K), D54.1 (K), D55.1 (K), D56.1 (K), D57.1 (K), D58.1 (K), D59.1 (K)
ROW4: A1.25 (GPIO19), D60.1 (K), D61.1 (K), D62.1 (K), D63.1 (K), D64.1 (K), D65.1 (K), D66.1 (K), D67.1 (K), D68.1 (K), D69.1 (K), D70.1 (K)

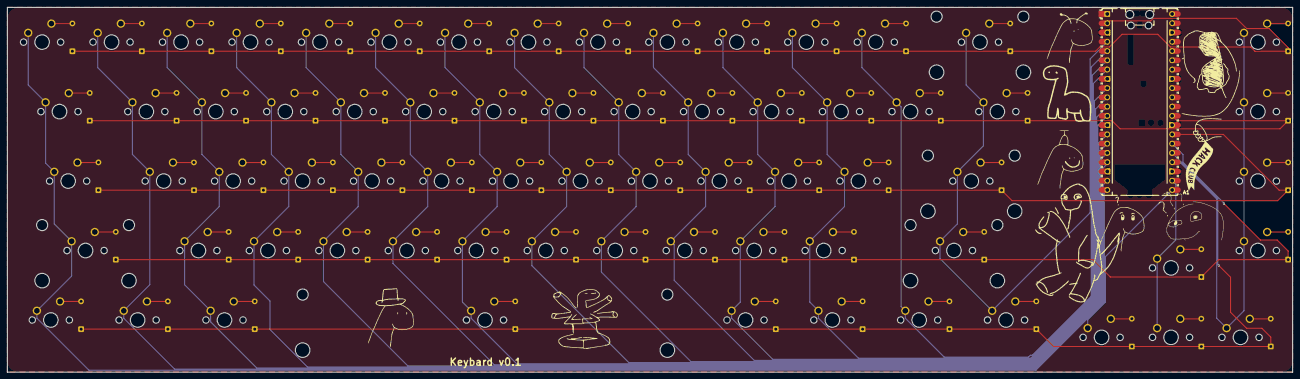
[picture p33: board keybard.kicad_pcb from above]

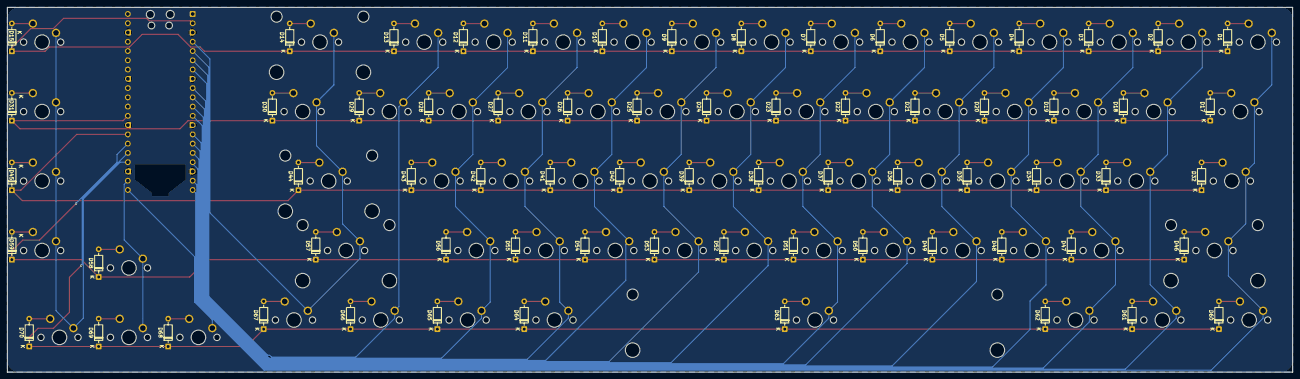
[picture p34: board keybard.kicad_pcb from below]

Board: 2 copper layers, 352.4 x 100.0 mm, 144 parts (69 on the bottom side), 92 nets.

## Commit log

2026-07-21 added cad files
    [bezel(left).step, bezel(right).step, bottom(left).step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]
2026-07-21 added assets
    [keybard.kicad_pcb]
2026-07-21 add assets
    [plate-2026-07-20T06_56_22.009Z.dxf]
2026-07-21 added BOM
    [BOM.csv]
2026-07-22 add screw holes to cad
    [bezel(left).step, bezel(right).step, bottom(left).step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]
